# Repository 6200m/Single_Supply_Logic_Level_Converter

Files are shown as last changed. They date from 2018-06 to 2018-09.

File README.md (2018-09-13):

SparkFun Single Supply Logic Level Converter
========================================

Single Supply Logic Level Converter (https://cdn.sparkfun.com/assets/parts/1/3/0/1/0/14765-SparkFun_Logic_Level_Converter_-_Single_Supply-01.jpg)

[*SparkFun Single Supply Logic Level Converter (PRT-14765)*](https://www.sparkfun.com/products/14765)

The SparkFun Single Supply Logic Level Converter is logic level and power supply translator in one small package. This little board breaks out the Texas Instruments TXB0104 4-bit bi-directional voltage-level translator with automatic direction sensing. With this logic level converter you will be able to use your 5V logic microcontroller with 3.3V sensors without the second power supply!

What makes this logic level converter truly special is the fact that you can supply it with 3.3V and it will create the 5V - meaning you can use your 3.3V system, and convert directly to another 5V sensor - and even power your sensor or other board!

This logic level converter provides 5V to the high side of the TXB0104 and the low side is programmable to 3.3V, 2.5V and 1.8V. Please keep in mind that the default low side voltage is 3.3V.

Repository Contents
-------------------
* **/Firmware** - Example code 
* **/Hardware** - Eagle design files (.brd, .sch)
* **/Production** - Production panel files (.brd)

Documentation
--------------
* **[Hookup Guide](https://learn.sparkfun.com/tutorials/single-supply-logic-level-converter-hook-up-guide)** - Basic hookup guide for the Single Supply Logic Level Converter.
* **[SparkFun Fritzing repo](https://github.com/sparkfun/Fritzing_Parts)** - Fritzing diagrams for SparkFun products.

Product Versions
----------------
* [PRT-14765](https://www.sparkfun.com/products/14765)- V1.0

License Information
-------------------

This product is _**open source**_! 

Please review the LICENSE.md file for license information. 

If you have any questions or concerns on licensing, please contact techsupport@sparkfun.com.

Distributed as-is; no warranty is given.

- Your friends at SparkFun.

_<COLLABORATION CREDIT>_

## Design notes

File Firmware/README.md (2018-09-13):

SparkFun <PRODUCT NAME> Firmware
=================================

Arduino example code used in the hookup guide for use with the single supply logic level converter.

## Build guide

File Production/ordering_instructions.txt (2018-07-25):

panel size, 221x156mm
PCB thickness, 1.6mm
number of layers, 2
soldermask color, Red
silkscreen color, White
oz copper, 1oz
finish, HASL lead free
stencils, none
pcs per panel, 40

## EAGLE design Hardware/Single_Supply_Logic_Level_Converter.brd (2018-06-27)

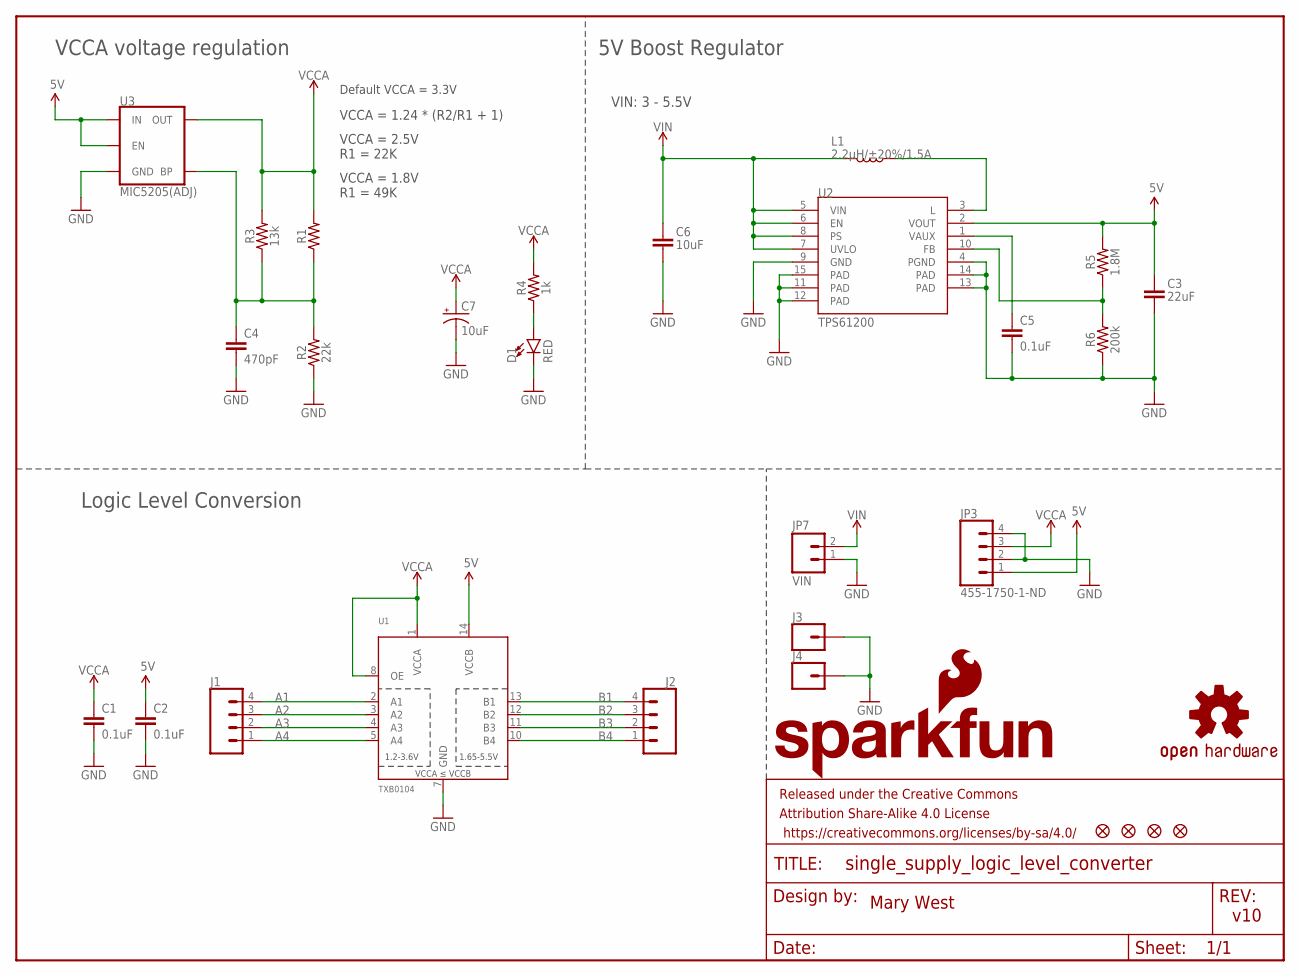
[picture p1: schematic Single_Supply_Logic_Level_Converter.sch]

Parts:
C1, C2: 0.1uF; 0603-CAP
C3: 22uF; 0805
C4: 470pF; 0603
C5: 0.1uF; 0603
C6: 10uF; 0603
C7: 10uF; EIA3216
D1: RED; LED-0603
FD1, FD2, FD3, FD4: FIDUCIALUFIDUCIAL; FIDUCIAL-MICRO
FRAME1: FRAME-LETTER; CREATIVE_COMMONS
J1, J2: CONN_04; 1X04
J3, J4: CONN_01; 1X01
JP3: 455-1750-1-ND; 1X04
JP7: VIN; 1X02
L1: 2.2µH/±20%/1.5A; INDUCTOR_2.2UH
LOGO1: SFE_LOGO_NAME_FLAME.1_INCH; SFE_LOGO_NAME_FLAME_.1
LOGO2: OSHW-LOGOS; OSHW-LOGO-S
R1: AXIAL-0.3
R2: 22k; 0603
R3: 13k; 0603
R4: 1k; 0603
R5: 1.8M; 0603
R6: 200k; 0603
U1: TXB0104; TSSOP14
U2: TPS61200; QFN-10_PAD
U3: MIC5205(ADJ); SOT23-5

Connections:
5V: C2.1, C3.1, JP3.1, R5.2, U1.14 (VCCB), U2.2 (VOUT), U3.1 (IN), U3.3 (EN)
A1: J1.4, U1.2 (A1)
A2: J1.3, U1.3 (A2)
A3: J1.2, U1.4 (A3)
A4: J1.1, U1.5 (A4)
B1: J2.4, U1.13 (B1)
B2: J2.3, U1.12 (B2)
B3: J2.2, U1.11 (B3)
B4: J2.1, U1.10 (B4)
FB: R5.1, R6.2, U2.10 (FB)
GND: C1.2, C2.2, C3.2, C4.2, C5.2, C6.2, C7.-, D1.C, J3.1, J4.1, JP3.2, JP3.4, JP7.1, R2.1, R6.1, U1.7 (GND), U2.4 (PGND), U2.9 (GND), U2.11 (PAD), U2.12 (PAD), U2.13 (PAD), U2.14 (PAD), U2.15 (PAD), U3.2 (GND)
unnamed: D1.A, R4.1
unnamed: L1.P$1 (1), U2.3 (L)
unnamed: C5.1, U2.1 (VAUX)
unnamed: C4.1, R1.P$1 (1), R2.2, R3.1, U3.4 (BP)
VCCA: C1.1, C7.+, JP3.3, R1.P$2 (2), R3.2, R4.2, U1.1 (VCCA), U1.8 (OE), U3.5 (OUT)
VIN: C6.1, JP7.2, L1.P$2 (2), U2.5 (VIN), U2.6 (EN), U2.7 (UVLO), U2.8 (PS)

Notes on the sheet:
Mary West
v10
VIN: 3 - 5.5V
Default VCCA = 3.3V
Logic Level Conversion
VCCA voltage regulation
5V Boost Regulator
VCCA = 1.24 * (R2/R1 + 1)
VCCA = 2.5V R1 = 22K
VCCA = 1.8V R1 = 49K

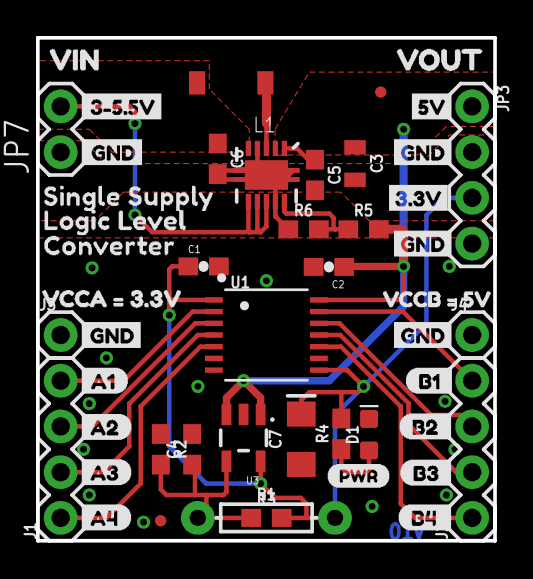
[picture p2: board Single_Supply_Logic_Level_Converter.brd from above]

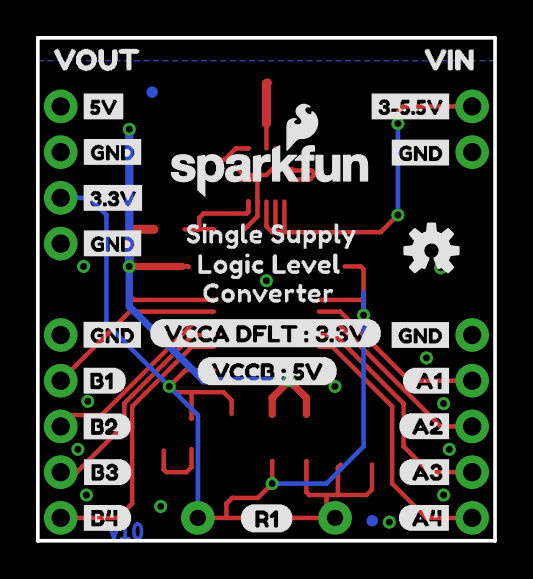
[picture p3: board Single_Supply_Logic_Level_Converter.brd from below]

Board: 2 copper layers, 25.4 x 27.9 mm, 79 parts (28 on the bottom side), 17 nets.

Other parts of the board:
U$7, U$24, U$31, U$34, U$35, U$40, U$41, U$52, U$54, U$55: GND0
U$8, U$38: VIN1
U$9: A10
U$10, U$43: CONVERTER0
U$11, U$45: LOGIC_LEVEL2
U$12, U$46: SINGLE_SUPPLY1
U$13: B1_12
U$14: A21
U$15: A32
U$16: A43
U$17: B14
U$18: B25
U$19: B2_11
U$20: B3_10
U$21, U$39: 3#5#5V3
U$22: B4_9
U$23, U$53: 3#3V2
U$25: A14
U$26: A28
U$27, U$44: VOUT2
U$28: A35
U$29: PWR0
U$30: A46
U$32, U$51: 5V1
U$33: B36
U$36: VCCA_#_3#3V0
U$42: B47
U$47: VCCA_DFLT_#_3#3V0
U$48: VCCB_#_5V0
U$49: R10
U$56: VCCB_#_5V1

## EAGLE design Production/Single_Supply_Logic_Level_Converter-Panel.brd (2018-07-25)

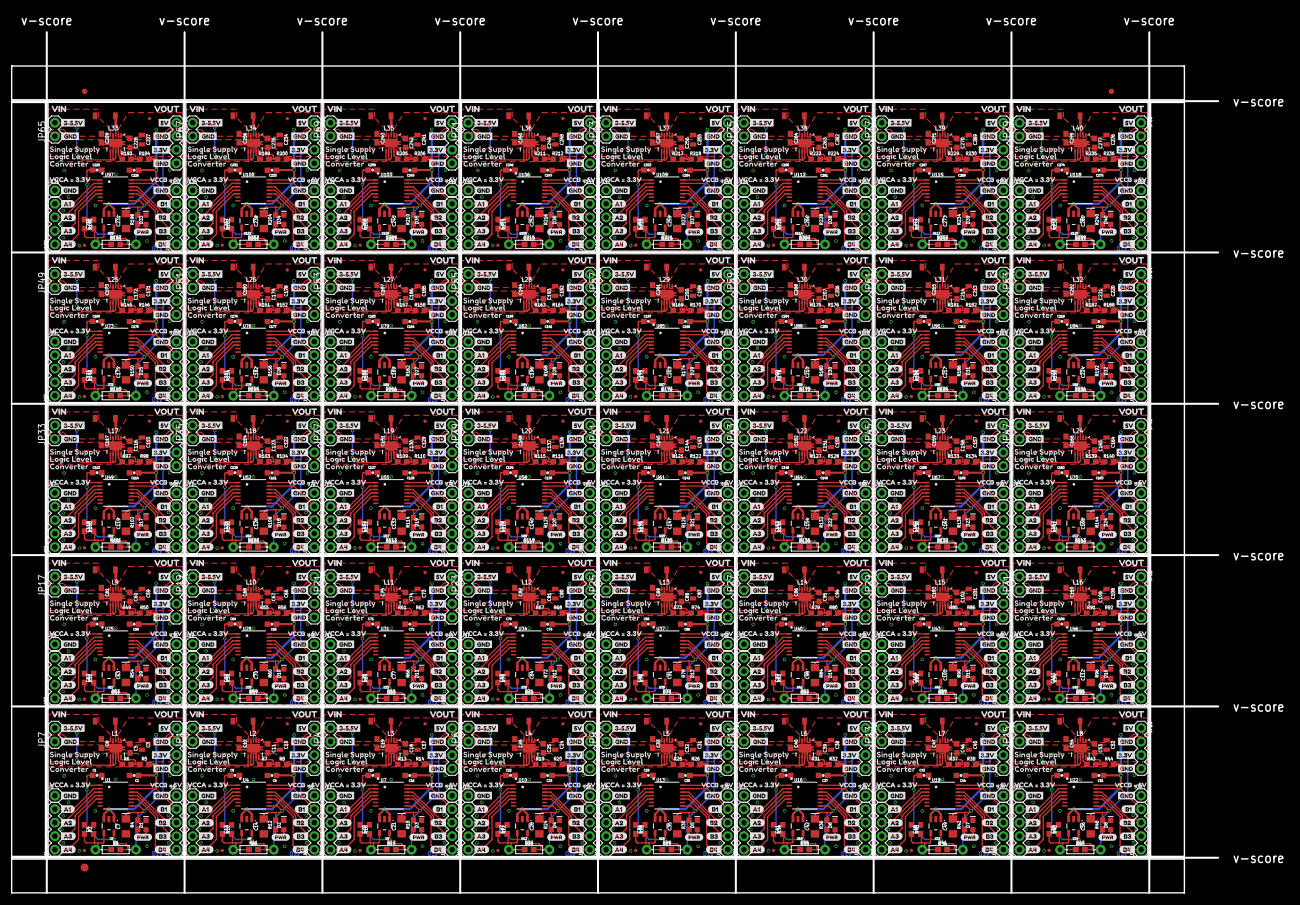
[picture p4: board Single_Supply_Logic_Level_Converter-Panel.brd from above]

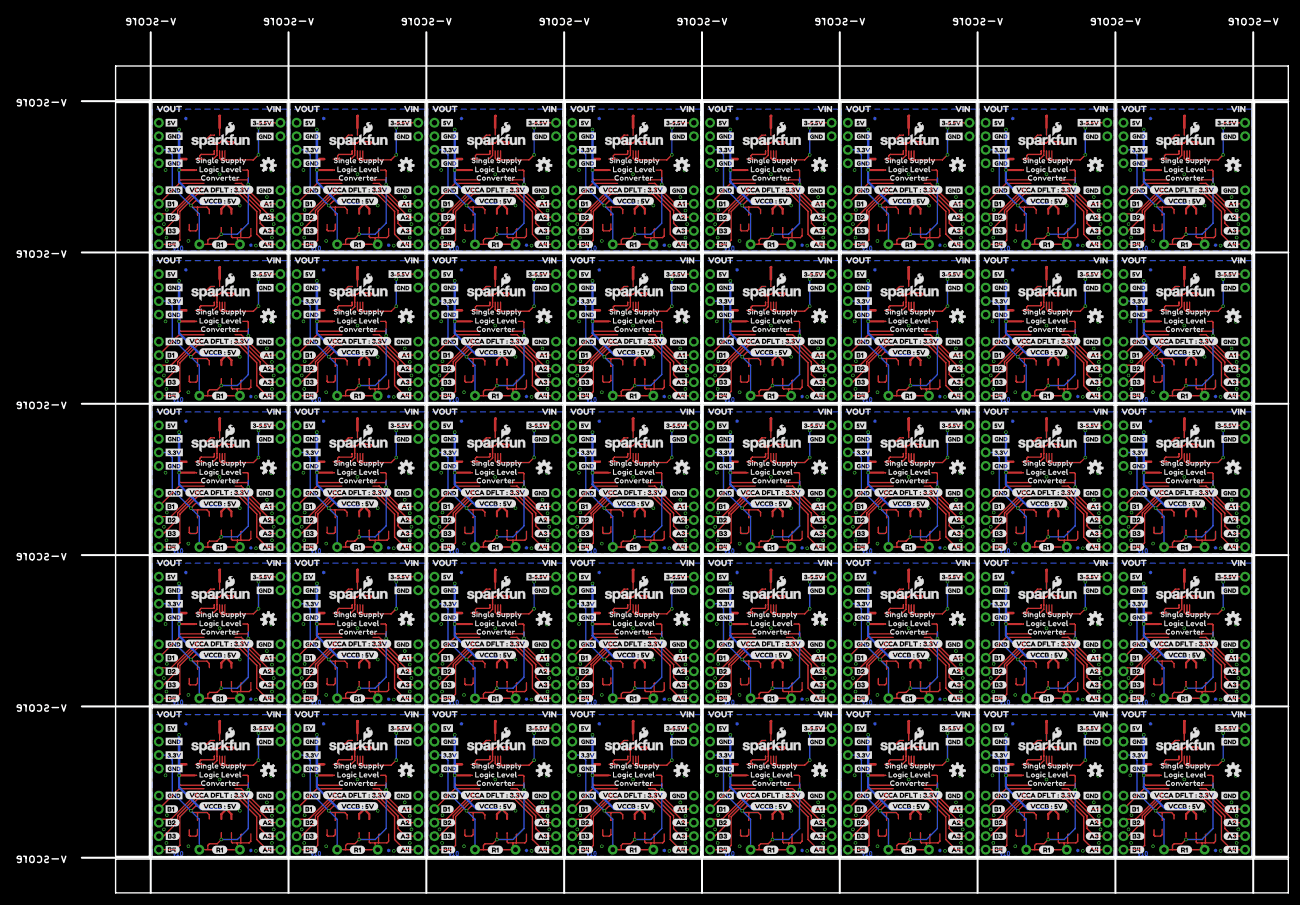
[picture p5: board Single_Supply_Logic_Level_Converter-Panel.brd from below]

Board: 2 copper layers, 226.8 x 161.8 mm, 3123 parts (1120 on the bottom side), 680 nets.

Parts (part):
C1, C2, C8, C9, C15, C16, C22, C23, C29, C30, C36, C37, C43, C44, C50, C51, C57, C58, C64, C65, C71, C72, C78, C79, C85, C86, C92, C93, C99, C100, C106, C107, C113, C114, C120, C121, C127, C128, C134, C135, C141, C142, C148, C149, C155, C156, C162, C163, C169, C170, C176, C177, C183, C184, C190, C191, C197, C198, C204, C205, C211, C212, C218, C219, C225, C226, C232, C233, C239, C240, C246, C247, C253, C254, C260, C261, C267, C268, C274, C275: 0.1uF; 0603-CAP
C3, C10, C17, C24, C31, C38, C45, C52, C59, C66, C73, C80, C87, C94, C101, C108, C115, C122, C129, C136, C143, C150, C157, C164, C171, C178, C185, C192, C199, C206, C213, C220, C227, C234, C241, C248, C255, C262, C269, C276: 22uF; 0805
C4, C13, C20, C27, C34, C41, C48, C55, C62, C69, C76, C83, C90, C97, C104, C111, C118, C125, C132, C139, C146, C153, C160, C167, C174, C181, C188, C195, C202, C209, C216, C223, C230, C237, C244, C251, C258, C265, C272, C279: 470pF; 0603
C5, C11, C18, C25, C32, C39, C46, C53, C60, C67, C74, C81, C88, C95, C102, C109, C116, C123, C130, C137, C144, C151, C158, C165, C172, C179, C186, C193, C200, C207, C214, C221, C228, C235, C242, C249, C256, C263, C270, C277: 0.1uF; 0603
C6, C12, C19, C26, C33, C40, C47, C54, C61, C68, C75, C82, C89, C96, C103, C110, C117, C124, C131, C138, C145, C152, C159, C166, C173, C180, C187, C194, C201, C208, C215, C222, C229, C236, C243, C250, C257, C264, C271, C278: 10uF; 0603
C7, C14, C21, C28, C35, C42, C49, C56, C63, C70, C77, C84, C91, C98, C105, C112, C119, C126, C133, C140, C147, C154, C161, C168, C175, C182, C189, C196, C203, C210, C217, C224, C231, C238, C245, C252, C259, C266, C273, C280: 10uF; EIA3216
D1, D2, D3, D4, D5, D6, D7, D8, D9, D10, D11, D12, D13, D14, D15, D16, D17, D18, D19, D20, D21, D22, D23, D24, D25, D26, D27, D28, D29, D30, D31, D32, D33, D34, D35, D36, D37, D38, D39, D40: RED; LED-0603
E$1, E$2: FIDUCIAL-1X2
E$3: FIDUCIAL-1.5X3
FD1, FD2, FD3, FD4, FD5, FD6, FD7, FD8, FD9, FD10, FD11, FD12, FD13, FD14, FD15, FD16, FD17, FD18, FD19, FD20, FD21, FD22, FD23, FD24, FD25, FD26, FD27, FD28, FD29, FD30, FD31, FD32, FD33, FD34, FD35, FD36, FD37, FD38, FD39, FD40, FD41, FD42, FD43, FD44, FD45, FD46, FD47, FD48, FD49, FD50, FD51, FD52, FD53, FD54, FD55, FD56, FD57, FD58, FD59, FD60, FD61, FD62, FD63, FD64, FD65, FD66, FD67, FD68, FD69, FD70, FD71, FD72, FD73, FD74, FD75, FD76, FD77, FD78, FD79, FD80, FD81, FD82, FD83, FD84, FD85, FD86, FD87, FD88, FD89, FD90, FD91, FD92, FD93, FD94, FD95, FD96, FD97, FD98, FD99, FD100, FD101, FD102, FD103, FD104, FD105, FD106, FD107, FD108, FD109, FD110, FD111, FD112, FD113, FD114, FD115, FD116, FD117, FD118, FD119, FD120, FD121, FD122, FD123, FD124, FD125, FD126, FD127, FD128, FD129, FD130, FD131, FD132, FD133, FD134, FD135, FD136, FD137, FD138, FD139, FD140, FD141, FD142, FD143, FD144, FD145, FD146, FD147, FD148, FD149, FD150, FD151, FD152, FD153, FD154, FD155, FD156, FD157, FD158, FD159, FD160: FIDUCIALUFIDUCIAL; FIDUCIAL-MICRO
J1, J2, J5, J6, J9, J10, J13, J14, J17, J18, J21, J22, J25, J26, J29, J30, J33, J34, J37, J38, J41, J42, J45, J46, J49, J50, J53, J54, J57, J58, J61, J62, J65, J66, J69, J70, J73, J74, J77, J78, J81, J82, J85, J86, J89, J90, J93, J94, J97, J98, J101, J102, J105, J106, J109, J110, J113, J114, J117, J118, J121, J122, J125, J126, J129, J130, J133, J134, J137, J138, J141, J142, J145, J146, J149, J150, J153, J154, J157, J158: 1X04
J3, J4, J7, J8, J11, J12, J15, J16, J19, J20, J23, J24, J27, J28, J31, J32, J35, J36, J39, J40, J43, J44, J47, J48, J51, J52, J55, J56, J59, J60, J63, J64, J67, J68, J71, J72, J75, J76, J79, J80, J83, J84, J87, J88, J91, J92, J95, J96, J99, J100, J103, J104, J107, J108, J111, J112, J115, J116, J119, J120, J123, J124, J127, J128, J131, J132, J135, J136, J139, J140, J143, J144, J147, J148, J151, J152, J155, J156, J159, J160: 1X01
JP1, JP4, JP6, JP7, JP9, JP11, JP13, JP15, JP17, JP19, JP21, JP23, JP25, JP27, JP29, JP31, JP33, JP35, JP37, JP39, JP41, JP43, JP45, JP47, JP49, JP51, JP53, JP55, JP57, JP59, JP61, JP63, JP65, JP67, JP69, JP71, JP73, JP75, JP77, JP79: VIN; 1X02
JP2, JP3, JP5, JP8, JP10, JP12, JP14, JP16, JP18, JP20, JP22, JP24, JP26, JP28, JP30, JP32, JP34, JP36, JP38, JP40, JP42, JP44, JP46, JP48, JP50, JP52, JP54, JP56, JP58, JP60, JP62, JP64, JP66, JP68, JP70, JP72, JP74, JP76, JP78, JP80: 455-1750-1-ND; 1X04
L1, L2, L3, L4, L5, L6, L7, L8, L9, L10, L11, L12, L13, L14, L15, L16, L17, L18, L19, L20, L21, L22, L23, L24, L25, L26, L27, L28, L29, L30, L31, L32, L33, L34, L35, L36, L37, L38, L39, L40: 2.2µH/±20%/1.5A; INDUCTOR_2.2UH
LOGO1, LOGO4, LOGO6, LOGO8, LOGO10, LOGO12, LOGO14, LOGO16, LOGO18, LOGO20, LOGO22, LOGO24, LOGO26, LOGO28, LOGO30, LOGO32, LOGO34, LOGO36, LOGO38, LOGO40, LOGO42, LOGO44, LOGO46, LOGO48, LOGO50, LOGO52, LOGO54, LOGO56, LOGO58, LOGO60, LOGO62, LOGO64, LOGO66, LOGO68, LOGO70, LOGO72, LOGO74, LOGO76, LOGO78, LOGO80: SFE_LOGO_NAME_FLAME.1_INCH; SFE_LOGO_NAME_FLAME_.1
LOGO2, LOGO3, LOGO5, LOGO7, LOGO9, LOGO11, LOGO13, LOGO15, LOGO17, LOGO19, LOGO21, LOGO23, LOGO25, LOGO27, LOGO29, LOGO31, LOGO33, LOGO35, LOGO37, LOGO39, LOGO41, LOGO43, LOGO45, LOGO47, LOGO49, LOGO51, LOGO53, LOGO55, LOGO57, LOGO59, LOGO61, LOGO63, LOGO65, LOGO67, LOGO69, LOGO71, LOGO73, LOGO75, LOGO77, LOGO79: OSHW-LOGOS; OSHW-LOGO-S
R1, R11, R17, R23, R29, R35, R41, R47, R53, R59, R65, R71, R77, R83, R89, R95, R101, R107, R113, R119, R125, R131, R137, R143, R149, R155, R161, R167, R173, R179, R185, R191, R197, R203, R209, R215, R221, R227, R233, R239: AXIAL-0.3
R2, R10, R16, R22, R28, R34, R40, R46, R52, R58, R64, R70, R76, R82, R88, R94, R100, R106, R112, R118, R124, R130, R136, R142, R148, R154, R160, R166, R172, R178, R184, R190, R196, R202, R208, R214, R220, R226, R232, R238: 22k; 0603
R3, R9, R15, R21, R27, R33, R39, R45, R51, R57, R63, R69, R75, R81, R87, R93, R99, R105, R111, R117, R123, R129, R135, R141, R147, R153, R159, R165, R171, R177, R183, R189, R195, R201, R207, R213, R219, R225, R231, R237: 13k; 0603
R4, R12, R18, R24, R30, R36, R42, R48, R54, R60, R66, R72, R78, R84, R90, R96, R102, R108, R114, R120, R126, R132, R138, R144, R150, R156, R162, R168, R174, R180, R186, R192, R198, R204, R210, R216, R222, R228, R234, R240: 1k; 0603
R5, R8, R14, R20, R26, R32, R38, R44, R50, R56, R62, R68, R74, R80, R86, R92, R98, R104, R110, R116, R122, R128, R134, R140, R146, R152, R158, R164, R170, R176, R182, R188, R194, R200, R206, R212, R218, R224, R230, R236: 1.8M; 0603
R6, R7, R13, R19, R25, R31, R37, R43, R49, R55, R61, R67, R73, R79, R85, R91, R97, R103, R109, R115, R121, R127, R133, R139, R145, R151, R157, R163, R169, R175, R181, R187, R193, R199, R205, R211, R217, R223, R229, R235: 200k; 0603
U1, U4, U7, U10, U13, U16, U19, U22, U25, U28, U31, U34, U37, U40, U43, U46, U49, U52, U55, U58, U61, U64, U67, U70, U73, U76, U79, U82, U85, U88, U91, U94, U97, U100, U103, U106, U109, U112, U115, U118: TXB0104; TSSOP14
U2, U5, U8, U11, U14, U17, U20, U23, U26, U29, U32, U35, U38, U41, U44, U47, U50, U53, U56, U59, U62, U65, U68, U71, U74, U77, U80, U83, U86, U89, U92, U95, U98, U101, U104, U107, U110, U113, U116, U119: TPS61200; QFN-10_PAD
U3, U6, U9, U12, U15, U18, U21, U24, U27, U30, U33, U36, U39, U42, U45, U48, U51, U54, U57, U60, U63, U66, U69, U72, U75, U78, U81, U84, U87, U90, U93, U96, U99, U102, U105, U108, U111, U114, U117, U120: MIC5205(ADJ); SOT23-5
U$1, U$29, U$97, U$145, U$193, U$241, U$289, U$337, U$385, U$433, U$481, U$529, U$577, U$625, U$673, U$721, U$769, U$817, U$865, U$913, U$961, U$1009, U$1057, U$1105, U$1153, U$1201, U$1249, U$1297, U$1345, U$1393, U$1441, U$1489, U$1537, U$1585, U$1633, U$1681, U$1729, U$1777, U$1825, U$1873: PWR0
U$2, U$5, U$10, U$43, U$98, U$101, U$146, U$149, U$194, U$197, U$242, U$245, U$290, U$293, U$338, U$341, U$386, U$389, U$434, U$437, U$482, U$485, U$530, U$533, U$578, U$581, U$626, U$629, U$674, U$677, U$722, U$725, U$770, U$773, U$818, U$821, U$866, U$869, U$914, U$917, U$962, U$965, U$1010, U$1013, U$1058, U$1061, U$1106, U$1109, U$1154, U$1157, U$1202, U$1205, U$1250, U$1253, U$1298, U$1301, U$1346, U$1349, U$1394, U$1397, U$1442, U$1445, U$1490, U$1493, U$1538, U$1541, U$1586, U$1589, U$1634, U$1637, U$1682, U$1685, U$1730, U$1733, U$1778, U$1781, U$1826, U$1829, U$1874, U$1877: CONVERTER0
U$3, U$6, U$11, U$45, U$99, U$102, U$147, U$150, U$195, U$198, U$243, U$246, U$291, U$294, U$339, U$342, U$387, U$390, U$435, U$438, U$483, U$486, U$531, U$534, U$579, U$582, U$627, U$630, U$675, U$678, U$723, U$726, U$771, U$774, U$819, U$822, U$867, U$870, U$915, U$918, U$963, U$966, U$1011, U$1014, U$1059, U$1062, U$1107, U$1110, U$1155, U$1158, U$1203, U$1206, U$1251, U$1254, U$1299, U$1302, U$1347, U$1350, U$1395, U$1398, U$1443, U$1446, U$1491, U$1494, U$1539, U$1542, U$1587, U$1590, U$1635, U$1638, U$1683, U$1686, U$1731, U$1734, U$1779, U$1782, U$1827, U$1830, U$1875, U$1878: LOGIC_LEVEL2
U$4, U$12, U$37, U$46, U$100, U$103, U$148, U$151, U$196, U$199, U$244, U$247, U$292, U$295, U$340, U$343, U$388, U$391, U$436, U$439, U$484, U$487, U$532, U$535, U$580, U$583, U$628, U$631, U$676, U$679, U$724, U$727, U$772, U$775, U$820, U$823, U$868, U$871, U$916, U$919, U$964, U$967, U$1012, U$1015, U$1060, U$1063, U$1108, U$1111, U$1156, U$1159, U$1204, U$1207, U$1252, U$1255, U$1300, U$1303, U$1348, U$1351, U$1396, U$1399, U$1444, U$1447, U$1492, U$1495, U$1540, U$1543, U$1588, U$1591, U$1636, U$1639, U$1684, U$1687, U$1732, U$1735, U$1780, U$1783, U$1828, U$1831, U$1876, U$1879: SINGLE_SUPPLY1
U$7, U$24, U$31, U$34, U$35, U$40, U$41, U$52, U$54, U$55, U$57, U$58, U$68, U$70, U$71, U$73, U$74, U$76, U$78, U$79, U$105, U$106, U$116, U$118, U$119, U$121, U$122, U$124, U$126, U$127, U$153, U$154, U$164, U$166, U$167, U$169, U$170, U$172, U$174, U$175, U$201, U$202, U$212, U$214, U$215, U$217, U$218, U$220, U$222, U$223, U$249, U$250, U$260, U$262, U$263, U$265, U$266, U$268, U$270, U$271, U$297, U$298, U$308, U$310, U$311, U$313, U$314, U$316, U$318, U$319, U$345, U$346, U$356, U$358, U$359, U$361, U$362, U$364, U$366, U$367, U$393, U$394, U$404, U$406, U$407, U$409, U$410, U$412, U$414, U$415, U$441, U$442, U$452, U$454, U$455, U$457, U$458, U$460, U$462, U$463, U$489, U$490, U$500, U$502, U$503, U$505, U$506, U$508, U$510, U$511, U$537, U$538, U$548, U$550, U$551, U$553, U$554, U$556, U$558, U$559, U$585, U$586, U$596, U$598, U$599, U$601, U$602, U$604, U$606, U$607, U$633, U$634, U$644, U$646, U$647, U$649, U$650, U$652, U$654, U$655, U$681, U$682, U$692, U$694, U$695, U$697, U$698, U$700, U$702, U$703, U$729, U$730, U$740, U$742, U$743, U$745, U$746, U$748, U$750, U$751, U$777, U$778, U$788, U$790, U$791, U$793, U$794, U$796, U$798, U$799, U$825, U$826, U$836, U$838, U$839, U$841, U$842, U$844, U$846, U$847, U$873, U$874, U$884, U$886, U$887, U$889, U$890, U$892, U$894, U$895, U$921, U$922, U$932, U$934, U$935, U$937, U$938, U$940, U$942, U$943, U$969, U$970, U$980, U$982, U$983, U$985, U$986, U$988, U$990, U$991, U$1017, U$1018, U$1028, U$1030, U$1031, U$1033, U$1034, U$1036, U$1038, U$1039, U$1065, U$1066, U$1076, U$1078, U$1079, U$1081, U$1082, U$1084, U$1086, U$1087, U$1113, U$1114, U$1124, U$1126, U$1127, U$1129, U$1130, U$1132, U$1134, U$1135, U$1161, U$1162, U$1172, U$1174, U$1175, U$1177, U$1178, U$1180, U$1182, U$1183, U$1209, U$1210, U$1220, U$1222, U$1223, U$1225, U$1226, U$1228, U$1230, U$1231, U$1257, U$1258, U$1268, U$1270, U$1271, U$1273, U$1274, U$1276, U$1278, U$1279, U$1305, U$1306, U$1316, U$1318, U$1319, U$1321, U$1322, U$1324, U$1326, U$1327, U$1353, U$1354, U$1364, U$1366, U$1367, U$1369, U$1370, U$1372, U$1374, U$1375, U$1401, U$1402, U$1412, U$1414, U$1415, U$1417, U$1418, U$1420, U$1422, U$1423, U$1449, U$1450, U$1460, U$1462, U$1463, U$1465, U$1466, U$1468, U$1470, U$1471, U$1497, U$1498, U$1508, U$1510, U$1511, U$1513, U$1514, U$1516, U$1518, U$1519, U$1545, U$1546, U$1556, U$1558, U$1559, U$1561, U$1562, U$1564, U$1566, U$1567, U$1593, U$1594, U$1604, U$1606, U$1607, U$1609, U$1610, U$1612, U$1614, U$1615, U$1641, U$1642, U$1652, U$1654, U$1655, U$1657, U$1658, U$1660, U$1662, U$1663, U$1689, U$1690, U$1700, U$1702, U$1703, U$1705, U$1706, U$1708, U$1710, U$1711, U$1737, U$1738, U$1748, U$1750, U$1751, U$1753, U$1754, U$1756, U$1758, U$1759, U$1785, U$1786, U$1796, U$1798, U$1799, U$1801, U$1802, U$1804, U$1806, U$1807, U$1833, U$1834, U$1844, U$1846, U$1847, U$1849, U$1850, U$1852, U$1854, U$1855, U$1881, U$1882, U$1892, U$1894, U$1895, U$1897, U$1898, U$1900, U$1902, U$1903: GND0
U$8, U$38, U$88, U$92, U$136, U$140, U$184, U$188, U$232, U$236, U$280, U$284, U$328, U$332, U$376, U$380, U$424, U$428, U$472, U$476, U$520, U$524, U$568, U$572, U$616, U$620, U$664, U$668, U$712, U$716, U$760, U$764, U$808, U$812, U$856, U$860, U$904, U$908, U$952, U$956, U$1000, U$1004, U$1048, U$1052, U$1096, U$1100, U$1144, U$1148, U$1192, U$1196, U$1240, U$1244, U$1288, U$1292, U$1336, U$1340, U$1384, U$1388, U$1432, U$1436, U$1480, U$1484, U$1528, U$1532, U$1576, U$1580, U$1624, U$1628, U$1672, U$1676, U$1720, U$1724, U$1768, U$1772, U$1816, U$1820, U$1864, U$1868, U$1912, U$1916: VIN1
U$9, U$80, U$128, U$176, U$224, U$272, U$320, U$368, U$416, U$464, U$512, U$560, U$608, U$656, U$704, U$752, U$800, U$848, U$896, U$944, U$992, U$1040, U$1088, U$1136, U$1184, U$1232, U$1280, U$1328, U$1376, U$1424, U$1472, U$1520, U$1568, U$1616, U$1664, U$1712, U$1760, U$1808, U$1856, U$1904: A10
U$13, U$63, U$111, U$159, U$207, U$255, U$303, U$351, U$399, U$447, U$495, U$543, U$591, U$639, U$687, U$735, U$783, U$831, U$879, U$927, U$975, U$1023, U$1071, U$1119, U$1167, U$1215, U$1263, U$1311, U$1359, U$1407, U$1455, U$1503, U$1551, U$1599, U$1647, U$1695, U$1743, U$1791, U$1839, U$1887: B1_12
U$14, U$81, U$129, U$177, U$225, U$273, U$321, U$369, U$417, U$465, U$513, U$561, U$609, U$657, U$705, U$753, U$801, U$849, U$897, U$945, U$993, U$1041, U$1089, U$1137, U$1185, U$1233, U$1281, U$1329, U$1377, U$1425, U$1473, U$1521, U$1569, U$1617, U$1665, U$1713, U$1761, U$1809, U$1857, U$1905: A21
U$15, U$82, U$130, U$178, U$226, U$274, U$322, U$370, U$418, U$466, U$514, U$562, U$610, U$658, U$706, U$754, U$802, U$850, U$898, U$946, U$994, U$1042, U$1090, U$1138, U$1186, U$1234, U$1282, U$1330, U$1378, U$1426, U$1474, U$1522, U$1570, U$1618, U$1666, U$1714, U$1762, U$1810, U$1858, U$1906: A32
U$16, U$83, U$131, U$179, U$227, U$275, U$323, U$371, U$419, U$467, U$515, U$563, U$611, U$659, U$707, U$755, U$803, U$851, U$899, U$947, U$995, U$1043, U$1091, U$1139, U$1187, U$1235, U$1283, U$1331, U$1379, U$1427, U$1475, U$1523, U$1571, U$1619, U$1667, U$1715, U$1763, U$1811, U$1859, U$1907: A43
U$17, U$84, U$132, U$180, U$228, U$276, U$324, U$372, U$420, U$468, U$516, U$564, U$612, U$660, U$708, U$756, U$804, U$852, U$900, U$948, U$996, U$1044, U$1092, U$1140, U$1188, U$1236, U$1284, U$1332, U$1380, U$1428, U$1476, U$1524, U$1572, U$1620, U$1668, U$1716, U$1764, U$1812, U$1860, U$1908: B14
U$18, U$85, U$133, U$181, U$229, U$277, U$325, U$373, U$421, U$469, U$517, U$565, U$613, U$661, U$709, U$757, U$805, U$853, U$901, U$949, U$997, U$1045, U$1093, U$1141, U$1189, U$1237, U$1285, U$1333, U$1381, U$1429, U$1477, U$1525, U$1573, U$1621, U$1669, U$1717, U$1765, U$1813, U$1861, U$1909: B25
U$19, U$64, U$112, U$160, U$208, U$256, U$304, U$352, U$400, U$448, U$496, U$544, U$592, U$640, U$688, U$736, U$784, U$832, U$880, U$928, U$976, U$1024, U$1072, U$1120, U$1168, U$1216, U$1264, U$1312, U$1360, U$1408, U$1456, U$1504, U$1552, U$1600, U$1648, U$1696, U$1744, U$1792, U$1840, U$1888: B2_11
U$20, U$65, U$113, U$161, U$209, U$257, U$305, U$353, U$401, U$449, U$497, U$545, U$593, U$641, U$689, U$737, U$785, U$833, U$881, U$929, U$977, U$1025, U$1073, U$1121, U$1169, U$1217, U$1265, U$1313, U$1361, U$1409, U$1457, U$1505, U$1553, U$1601, U$1649, U$1697, U$1745, U$1793, U$1841, U$1889: B3_10
U$21, U$39, U$50, U$72, U$104, U$120, U$152, U$168, U$200, U$216, U$248, U$264, U$296, U$312, U$344, U$360, U$392, U$408, U$440, U$456, U$488, U$504, U$536, U$552, U$584, U$600, U$632, U$648, U$680, U$696, U$728, U$744, U$776, U$792, U$824, U$840, U$872, U$888, U$920, U$936, U$968, U$984, U$1016, U$1032, U$1064, U$1080, U$1112, U$1128, U$1160, U$1176, U$1208, U$1224, U$1256, U$1272, U$1304, U$1320, U$1352, U$1368, U$1400, U$1416, U$1448, U$1464, U$1496, U$1512, U$1544, U$1560, U$1592, U$1608, U$1640, U$1656, U$1688, U$1704, U$1736, U$1752, U$1784, U$1800, U$1832, U$1848, U$1880, U$1896: 3#5#5V3
U$22, U$66, U$114, U$162, U$210, U$258, U$306, U$354, U$402, U$450, U$498, U$546, U$594, U$642, U$690, U$738, U$786, U$834, U$882, U$930, U$978, U$1026, U$1074, U$1122, U$1170, U$1218, U$1266, U$1314, U$1362, U$1410, U$1458, U$1506, U$1554, U$1602, U$1650, U$1698, U$1746, U$1794, U$1842, U$1890: B4_9
U$23, U$53, U$67, U$77, U$115, U$125, U$163, U$173, U$211, U$221, U$259, U$269, U$307, U$317, U$355, U$365, U$403, U$413, U$451, U$461, U$499, U$509, U$547, U$557, U$595, U$605, U$643, U$653, U$691, U$701, U$739, U$749, U$787, U$797, U$835, U$845, U$883, U$893, U$931, U$941, U$979, U$989, U$1027, U$1037, U$1075, U$1085, U$1123, U$1133, U$1171, U$1181, U$1219, U$1229, U$1267, U$1277, U$1315, U$1325, U$1363, U$1373, U$1411, U$1421, U$1459, U$1469, U$1507, U$1517, U$1555, U$1565, U$1603, U$1613, U$1651, U$1661, U$1699, U$1709, U$1747, U$1757, U$1795, U$1805, U$1843, U$1853, U$1891, U$1901: 3#3V2
U$25, U$59, U$107, U$155, U$203, U$251, U$299, U$347, U$395, U$443, U$491, U$539, U$587, U$635, U$683, U$731, U$779, U$827, U$875, U$923, U$971, U$1019, U$1067, U$1115, U$1163, U$1211, U$1259, U$1307, U$1355, U$1403, U$1451, U$1499, U$1547, U$1595, U$1643, U$1691, U$1739, U$1787, U$1835, U$1883: A14
U$26, U$60, U$108, U$156, U$204, U$252, U$300, U$348, U$396, U$444, U$492, U$540, U$588, U$636, U$684, U$732, U$780, U$828, U$876, U$924, U$972, U$1020, U$1068, U$1116, U$1164, U$1212, U$1260, U$1308, U$1356, U$1404, U$1452, U$1500, U$1548, U$1596, U$1644, U$1692, U$1740, U$1788, U$1836, U$1884: A28
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

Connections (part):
5V: C2.1, C3.1, JP3.1, R5.2, U1.14, U2.2, U3.1, U3.3
5V1: C9.1, C10.1, JP2.1, R8.2, U4.14, U5.2, U6.1, U6.3
5V2: C16.1, C17.1, JP5.1, R14.2, U7.14, U8.2, U9.1, U9.3
5V3: C23.1, C24.1, JP8.1, R20.2, U10.14, U11.2, U12.1, U12.3
5V4: C30.1, C31.1, JP10.1, R26.2, U13.14, U14.2, U15.1, U15.3
5V5: C37.1, C38.1, JP12.1, R32.2, U16.14, U17.2, U18.1, U18.3
5V6: C44.1, C45.1, JP14.1, R38.2, U19.14, U20.2, U21.1, U21.3
5V7: C51.1, C52.1, JP16.1, R44.2, U22.14, U23.2, U24.1, U24.3
5V8: C58.1, C59.1, JP18.1, R50.2, U25.14, U26.2, U27.1, U27.3
5V9: C65.1, C66.1, JP20.1, R56.2, U28.14, U29.2, U30.1, U30.3
5V10: C72.1, C73.1, JP22.1, R62.2, U31.14, U32.2, U33.1, U33.3
5V11: C79.1, C80.1, JP24.1, R68.2, U34.14, U35.2, U36.1, U36.3
5V12: C86.1, C87.1, JP26.1, R74.2, U37.14, U38.2, U39.1, U39.3
5V13: C93.1, C94.1, JP28.1, R80.2, U40.14, U41.2, U42.1, U42.3
5V14: C100.1, C101.1, JP30.1, R86.2, U43.14, U44.2, U45.1, U45.3
5V15: C107.1, C108.1, JP32.1, R92.2, U46.14, U47.2, U48.1, U48.3
5V16: C114.1, C115.1, JP34.1, R98.2, U49.14, U50.2, U51.1, U51.3
5V17: C121.1, C122.1, JP36.1, R104.2, U52.14, U53.2, U54.1, U54.3
5V18: C128.1, C129.1, JP38.1, R110.2, U55.14, U56.2, U57.1, U57.3
5V19: C135.1, C136.1, JP40.1, R116.2, U58.14, U59.2, U60.1, U60.3
5V20: C142.1, C143.1, JP42.1, R122.2, U61.14, U62.2, U63.1, U63.3
5V21: C149.1, C150.1, JP44.1, R128.2, U64.14, U65.2, U66.1, U66.3
5V22: C156.1, C157.1, JP46.1, R134.2, U67.14, U68.2, U69.1, U69.3
5V23: C163.1, C164.1, JP48.1, R140.2, U70.14, U71.2, U72.1, U72.3
5V24: C170.1, C171.1, JP50.1, R146.2, U73.14, U74.2, U75.1, U75.3
5V25: C177.1, C178.1, JP52.1, R152.2, U76.14, U77.2, U78.1, U78.3
5V26: C184.1, C185.1, JP54.1, R158.2, U79.14, U80.2, U81.1, U81.3
5V27: C191.1, C192.1, JP56.1, R164.2, U82.14, U83.2, U84.1, U84.3
5V28: C198.1, C199.1, JP58.1, R170.2, U85.14, U86.2, U87.1, U87.3
5V29: C205.1, C206.1, JP60.1, R176.2, U88.14, U89.2, U90.1, U90.3
5V30: C212.1, C213.1, JP62.1, R182.2, U91.14, U92.2, U93.1, U93.3
5V31: C219.1, C220.1, JP64.1, R188.2, U94.14, U95.2, U96.1, U96.3
5V32: C226.1, C227.1, JP66.1, R194.2, U97.14, U98.2, U99.1, U99.3
5V33: C233.1, C234.1, JP68.1, R200.2, U100.14, U101.2, U102.1, U102.3
5V34: C240.1, C241.1, JP70.1, R206.2, U103.14, U104.2, U105.1, U105.3
5V35: C247.1, C248.1, JP72.1, R212.2, U106.14, U107.2, U108.1, U108.3
5V36: C254.1, C255.1, JP74.1, R218.2, U109.14, U110.2, U111.1, U111.3
5V37: C261.1, C262.1, JP76.1, R224.2, U112.14, U113.2, U114.1, U114.3
5V38: C268.1, C269.1, JP78.1, R230.2, U115.14, U116.2, U117.1, U117.3
5V39: C275.1, C276.1, JP80.1, R236.2, U118.14, U119.2, U120.1, U120.3
A1: J1.4, U1.2
A2: J1.3, U1.3
A3: J1.2, U1.4
A4: J1.1, U1.5
A5: J5.3, U4.3
A6: J5.1, U4.5
A7: J5.2, U4.4
A8: J5.4, U4.2
A9: J9.3, U7.3
A10: J9.1, U7.5
A11: J9.2, U7.4
A12: J9.4, U7.2
A13: J13.3, U10.3
A14: J13.1, U10.5
A15: J13.2, U10.4
A16: J13.4, U10.2
A17: J17.3, U13.3
A18: J17.1, U13.5
A19: J17.2, U13.4
A20: J17.4, U13.2
A21: J21.3, U16.3
A22: J21.1, U16.5
A23: J21.2, U16.4
A24: J21.4, U16.2
A25: J25.3, U19.3
A26: J25.1, U19.5
A27: J25.2, U19.4
A28: J25.4, U19.2
A29: J29.3, U22.3
A30: J29.1, U22.5
A31: J29.2, U22.4
A32: J29.4, U22.2
A33: J33.3, U25.3
A34: J33.1, U25.5
A35: J33.2, U25.4
A36: J33.4, U25.2
A37: J37.3, U28.3
A38: J37.1, U28.5
A39: J37.2, U28.4
A40: J37.4, U28.2
A41: J41.3, U31.3
A42: J41.1, U31.5
A43: J41.2, U31.4
A44: J41.4, U31.2
A45: J45.3, U34.3
A46: J45.1, U34.5
A47: J45.2, U34.4
A48: J45.4, U34.2
A49: J49.3, U37.3
A50: J49.1, U37.5
A51: J49.2, U37.4
A52: J49.4, U37.2
A53: J53.3, U40.3
A54: J53.1, U40.5
A55: J53.2, U40.4
A56: J53.4, U40.2
A57: J57.3, U43.3
A58: J57.1, U43.5
A59: J57.2, U43.4
A60: J57.4, U43.2
A61: J61.3, U46.3
A62: J61.1, U46.5
A63: J61.2, U46.4
A64: J61.4, U46.2
A65: J65.3, U49.3
A66: J65.1, U49.5
A67: J65.2, U49.4
A68: J65.4, U49.2
A69: J69.3, U52.3
A70: J69.1, U52.5
A71: J69.2, U52.4
A72: J69.4, U52.2
A73: J73.3, U55.3
A74: J73.1, U55.5
A75: J73.2, U55.4
A76: J73.4, U55.2
A77: J77.3, U58.3
A78: J77.1, U58.5
A79: J77.2, U58.4
A80: J77.4, U58.2
A81: J81.3, U61.3
A82: J81.1, U61.5
A83: J81.2, U61.4
A84: J81.4, U61.2
A85: J85.3, U64.3
A86: J85.1, U64.5
A87: J85.2, U64.4
A88: J85.4, U64.2
A89: J89.3, U67.3
A90: J89.1, U67.5
A91: J89.2, U67.4
A92: J89.4, U67.2
A93: J93.3, U70.3
A94: J93.1, U70.5
A95: J93.2, U70.4
A96: J93.4, U70.2
A97: J97.3, U73.3
A98: J97.1, U73.5
A99: J97.2, U73.4
A100: J97.4, U73.2
A101: J101.3, U76.3
A102: J101.1, U76.5
A103: J101.2, U76.4
A104: J101.4, U76.2
A105: J105.3, U79.3
A106: J105.1, U79.5
A107: J105.2, U79.4
A108: J105.4, U79.2
A109: J109.3, U82.3
A110: J109.1, U82.5
A111: J109.2, U82.4
A112: J109.4, U82.2
A113: J113.3, U85.3
A114: J113.1, U85.5
A115: J113.2, U85.4
A116: J113.4, U85.2
A117: J117.3, U88.3
A118: J117.1, U88.5
A119: J117.2, U88.4
A120: J117.4, U88.2
A121: J121.3, U91.3
A122: J121.1, U91.5
A123: J121.2, U91.4
A124: J121.4, U91.2
A125: J125.3, U94.3
A126: J125.1, U94.5
A127: J125.2, U94.4
A128: J125.4, U94.2
A129: J129.3, U97.3
A130: J129.1, U97.5
A131: J129.2, U97.4
A132: J129.4, U97.2
A133: J133.3, U100.3
A134: J133.1, U100.5
A135: J133.2, U100.4
A136: J133.4, U100.2
A137: J137.3, U103.3
A138: J137.1, U103.5
A139: J137.2, U103.4
A140: J137.4, U103.2
A141: J141.3, U106.3
A142: J141.1, U106.5
A143: J141.2, U106.4
A144: J141.4, U106.2
A145: J145.3, U109.3
A146: J145.1, U109.5
A147: J145.2, U109.4
A148: J145.4, U109.2
A149: J149.3, U112.3
A150: J149.1, U112.5
A151: J149.2, U112.4
A152: J149.4, U112.2
A153: J153.3, U115.3
A154: J153.1, U115.5
A155: J153.2, U115.4
A156: J153.4, U115.2
A157: J157.3, U118.3
A158: J157.1, U118.5
A159: J157.2, U118.4
A160: J157.4, U118.2
B1: J2.4, U1.13
B2: J2.3, U1.12
B3: J2.2, U1.11
B4: J2.1, U1.10
B5: J6.4, U4.13
B6: J6.2, U4.11
B7: J6.1, U4.10
B8: J6.3, U4.12
B9: J10.4, U7.13
B10: J10.2, U7.11
B11: J10.1, U7.10
B12: J10.3, U7.12
B13: J14.4, U10.13
B14: J14.2, U10.11
B15: J14.1, U10.10
B16: J14.3, U10.12
B17: J18.4, U13.13
B18: J18.2, U13.11
B19: J18.1, U13.10
B20: J18.3, U13.12
B21: J22.4, U16.13
B22: J22.2, U16.11
B23: J22.1, U16.10
B24: J22.3, U16.12
B25: J26.4, U19.13
B26: J26.2, U19.11
B27: J26.1, U19.10
B28: J26.3, U19.12
B29: J30.4, U22.13
B30: J30.2, U22.11
B31: J30.1, U22.10
B32: J30.3, U22.12
B33: J34.4, U25.13
B34: J34.2, U25.11
B35: J34.1, U25.10
B36: J34.3, U25.12
B37: J38.4, U28.13
B38: J38.2, U28.11
B39: J38.1, U28.10
B40: J38.3, U28.12
B41: J42.4, U31.13
B42: J42.2, U31.11
B43: J42.1, U31.10
B44: J42.3, U31.12
B45: J46.4, U34.13
B46: J46.2, U34.11
B47: J46.1, U34.10
B48: J46.3, U34.12
B49: J50.4, U37.13
B50: J50.2, U37.11
B51: J50.1, U37.10
B52: J50.3, U37.12
B53: J54.4, U40.13
B54: J54.2, U40.11
B55: J54.1, U40.10
B56: J54.3, U40.12
B57: J58.4, U43.13
B58: J58.2, U43.11
B59: J58.1, U43.10
B60: J58.3, U43.12
B61: J62.4, U46.13
B62: J62.2, U46.11
B63: J62.1, U46.10
B64: J62.3, U46.12
B65: J66.4, U49.13
B66: J66.2, U49.11
B67: J66.1, U49.10
B68: J66.3, U49.12
B69: J70.4, U52.13
B70: J70.2, U52.11
B71: J70.1, U52.10
B72: J70.3, U52.12
B73: J74.4, U55.13
B74: J74.2, U55.11
B75: J74.1, U55.10
B76: J74.3, U55.12
B77: J78.4, U58.13
B78: J78.2, U58.11
B79: J78.1, U58.10
B80: J78.3, U58.12
B81: J82.4, U61.13
B82: J82.2, U61.11
B83: J82.1, U61.10
B84: J82.3, U61.12
B85: J86.4, U64.13
B86: J86.2, U64.11
B87: J86.1, U64.10
B88: J86.3, U64.12
B89: J90.4, U67.13
B90: J90.2, U67.11
B91: J90.1, U67.10
B92: J90.3, U67.12
B93: J94.4, U70.13
B94: J94.2, U70.11
B95: J94.1, U70.10
B96: J94.3, U70.12
B97: J98.4, U73.13
B98: J98.2, U73.11
B99: J98.1, U73.10
B100: J98.3, U73.12
B101: J102.4, U76.13
B102: J102.2, U76.11
B103: J102.1, U76.10
B104: J102.3, U76.12
B105: J106.4, U79.13
B106: J106.2, U79.11
B107: J106.1, U79.10
B108: J106.3, U79.12
B109: J110.4, U82.13
B110: J110.2, U82.11
B111: J110.1, U82.10
B112: J110.3, U82.12
B113: J114.4, U85.13
B114: J114.2, U85.11
B115: J114.1, U85.10
B116: J114.3, U85.12
B117: J118.4, U88.13
B118: J118.2, U88.11
B119: J118.1, U88.10
B120: J118.3, U88.12
B121: J122.4, U91.13
B122: J122.2, U91.11
B123: J122.1, U91.10
B124: J122.3, U91.12
B125: J126.4, U94.13
B126: J126.2, U94.11
B127: J126.1, U94.10
B128: J126.3, U94.12
B129: J130.4, U97.13
B130: J130.2, U97.11
B131: J130.1, U97.10
B132: J130.3, U97.12
B133: J134.4, U100.13
B134: J134.2, U100.11
B135: J134.1, U100.10
B136: J134.3, U100.12
B137: J138.4, U103.13
B138: J138.2, U103.11
B139: J138.1, U103.10
B140: J138.3, U103.12
B141: J142.4, U106.13
B142: J142.2, U106.11
B143: J142.1, U106.10
B144: J142.3, U106.12
B145: J146.4, U109.13
B146: J146.2, U109.11
B147: J146.1, U109.10
B148: J146.3, U109.12
B149: J150.4, U112.13
B150: J150.2, U112.11
B151: J150.1, U112.10
B152: J150.3, U112.12
B153: J154.4, U115.13
B154: J154.2, U115.11
B155: J154.1, U115.10
B156: J154.3, U115.12
B157: J158.4, U118.13
B158: J158.2, U118.11
B159: J158.1, U118.10
B160: J158.3, U118.12
FB: R5.1, R6.2, U2.10
FB1: R7.2, R8.1, U5.10
FB2: R13.2, R14.1, U8.10
FB3: R19.2, R20.1, U11.10
FB4: R25.2, R26.1, U14.10
FB5: R31.2, R32.1, U17.10
FB6: R37.2, R38.1, U20.10
FB7: R43.2, R44.1, U23.10
FB8: R49.2, R50.1, U26.10
FB9: R55.2, R56.1, U29.10
FB10: R61.2, R62.1, U32.10
FB11: R67.2, R68.1, U35.10
FB12: R73.2, R74.1, U38.10
FB13: R79.2, R80.1, U41.10
FB14: R85.2, R86.1, U44.10
FB15: R91.2, R92.1, U47.10
FB16: R97.2, R98.1, U50.10
FB17: R103.2, R104.1, U53.10
FB18: R109.2, R110.1, U56.10
FB19: R115.2, R116.1, U59.10
FB20: R121.2, R122.1, U62.10
FB21: R127.2, R128.1, U65.10
FB22: R133.2, R134.1, U68.10
FB23: R139.2, R140.1, U71.10
FB24: R145.2, R146.1, U74.10
FB25: R151.2, R152.1, U77.10
FB26: R157.2, R158.1, U80.10
FB27: R163.2, R164.1, U83.10
FB28: R169.2, R170.1, U86.10
FB29: R175.2, R176.1, U89.10
FB30: R181.2, R182.1, U92.10
FB31: R187.2, R188.1, U95.10
FB32: R193.2, R194.1, U98.10
FB33: R199.2, R200.1, U101.10
FB34: R205.2, R206.1, U104.10
FB35: R211.2, R212.1, U107.10
FB36: R217.2, R218.1, U110.10
FB37: R223.2, R224.1, U113.10
FB38: R229.2, R230.1, U116.10
FB39: R235.2, R236.1, U119.10
GND: C1.2, C2.2, C3.2, C4.2, C5.2, C6.2, C7.-, D1.C, J3.1, J4.1, JP3.2, JP3.4, JP7.1, R2.1, R6.1, U1.7, U2.4, U2.9, U2.11, U2.12, U2.13, U2.14, U2.15, U3.2
GND1: C8.2, C9.2, C10.2, C11.2, C12.2, C13.2, C14.-, D2.C, J7.1, J8.1, JP1.1, JP2.2, JP2.4, R7.1, R10.1, U4.7, U5.4, U5.9, U5.11, U5.12, U5.13, U5.14, U5.15, U6.2
GND2: C15.2, C16.2, C17.2, C18.2, C19.2, C20.2, C21.-, D3.C, J11.1, J12.1, JP4.1, JP5.2, JP5.4, R13.1, R16.1, U7.7, U8.4, U8.9, U8.11, U8.12, U8.13, U8.14, U8.15, U9.2
GND3: C22.2, C23.2, C24.2, C25.2, C26.2, C27.2, C28.-, D4.C, J15.1, J16.1, JP6.1, JP8.2, JP8.4, R19.1, R22.1, U10.7, U11.4, U11.9, U11.11, U11.12, U11.13, U11.14, U11.15, U12.2
GND4: C29.2, C30.2, C31.2, C32.2, C33.2, C34.2, C35.-, D5.C, J19.1, J20.1, JP9.1, JP10.2, JP10.4, R25.1, R28.1, U13.7, U14.4, U14.9, U14.11, U14.12, U14.13, U14.14, U14.15, U15.2
GND5: C36.2, C37.2, C38.2, C39.2, C40.2, C41.2, C42.-, D6.C, J23.1, J24.1, JP11.1, JP12.2, JP12.4, R31.1, R34.1, U16.7, U17.4, U17.9, U17.11, U17.12, U17.13, U17.14, U17.15, U18.2
GND6: C43.2, C44.2, C45.2, C46.2, C47.2, C48.2, C49.-, D7.C, J27.1, J28.1, JP13.1, JP14.2, JP14.4, R37.1, R40.1, U19.7, U20.4, U20.9, U20.11, U20.12, U20.13, U20.14, U20.15, U21.2
GND7: C50.2, C51.2, C52.2, C53.2, C54.2, C55.2, C56.-, D8.C, J31.1, J32.1, JP15.1, JP16.2, JP16.4, R43.1, R46.1, U22.7, U23.4, U23.9, U23.11, U23.12, U23.13, U23.14, U23.15, U24.2
GND8: C57.2, C58.2, C59.2, C60.2, C61.2, C62.2, C63.-, D9.C, J35.1, J36.1, JP17.1, JP18.2, JP18.4, R49.1, R52.1, U25.7, U26.4, U26.9, U26.11, U26.12, U26.13, U26.14, U26.15, U27.2
GND9: C64.2, C65.2, C66.2, C67.2, C68.2, C69.2, C70.-, D10.C, J39.1, J40.1, JP19.1, JP20.2, JP20.4, R55.1, R58.1, U28.7, U29.4, U29.9, U29.11, U29.12, U29.13, U29.14, U29.15, U30.2
GND10: C71.2, C72.2, C73.2, C74.2, C75.2, C76.2, C77.-, D11.C, J43.1, J44.1, JP21.1, JP22.2, JP22.4, R61.1, R64.1, U31.7, U32.4, U32.9, U32.11, U32.12, U32.13, U32.14, U32.15, U33.2
GND11: C78.2, C79.2, C80.2, C81.2, C82.2, C83.2, C84.-, D12.C, J47.1, J48.1, JP23.1, JP24.2, JP24.4, R67.1, R70.1, U34.7, U35.4, U35.9, U35.11, U35.12, U35.13, U35.14, U35.15, U36.2
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

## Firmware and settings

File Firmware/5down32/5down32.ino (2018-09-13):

/*
Single Supply Logic Level Converter Hookup Guide

This project will beep continuosly with a frequency proportional 
to distance. As objects get closer, the beep gets faster. 

Hardware:
 HC-SR04 Ultrasonic Sensor 
 Arduino Pro Mini 3.3V/8MHz
 SparkFun Single Supply Logic Level Converter
 Piezo Buzzer

*/


#define TRIG_PIN 10
#define ECHO_PIN 11
#define Beep 3

void setup() {
  Serial.begin (9600);
  pinMode(TRIG_PIN, OUTPUT);
  digitalWrite(TRIG_PIN, LOW);
  pinMode(Beep, OUTPUT);
}

void loop() {
  unsigned long t1;
  unsigned long t2;
  unsigned long pulse_width;
  float cm1;


  // Hold the trigger pin high for at least 10 us
  digitalWrite(TRIG_PIN, HIGH);
  delayMicroseconds(10);
  digitalWrite(TRIG_PIN, LOW);

  // Wait for pulse on echo pin
  while (digitalRead(ECHO_PIN) == 0 );

  // Measure how long the echo pin was held high (pulse width)
  // Note: the micros() counter will overflow after ~70 min
  t1 = micros();
  while (digitalRead(ECHO_PIN) == 1);
  t2 = micros();
  pulse_width = t2 - t1;

  // Calculate distance in centimeters.
  cm1 = pulse_width*0.034/2;
  if (cm1 >= 200 || cm1 <= 0){
    Serial.println("Out of range");
  }
  else {
    Serial.print(cm1);
    Serial.println(" cm");

    tone(Beep,528); 
    delay(100);
    noTone(Beep);
    delay(cm1);
    

  }
}

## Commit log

2018-05-23 updated VOUT programming
    [Single_Supply_Logic_Level_Converter.brd, Single_Supply_Logic_Level_Converter.sch]
2018-05-23 Vout voltage from Vreg directly
    [Single_Supply_Logic_Level_Converter.brd]
2018-05-24 resizing board to 1x1 inch
    [Single_Supply_Logic_Level_Converter.brd]
2018-05-29 Adding top ground plane
    [Single_Supply_Logic_Level_Converter.brd]
2018-05-30 Updating design per review
    [Single_Supply_Logic_Level_Converter.brd, Single_Supply_Logic_Level_Converter.sch]
2018-05-31 New labels
    [Single_Supply_Logic_Level_Converter.brd, Single_Supply_Logic_Level_Converter.sch]
2018-05-31 Added text for warnings and jumper settings
    [Single_Supply_Logic_Level_Converter.brd, Single_Supply_Logic_Level_Converter.sch]
2018-06-04 adding buzzard labels
    [Single_Supply_Logic_Level_Converter.brd, Single_Supply_Logic_Level_Converter.sch]
2018-06-04 changing voltage output programming
    [Single_Supply_Logic_Level_Converter.brd, Single_Supply_Logic_Level_Converter.sch]
2018-06-04 adding measurements
    [Single_Supply_Logic_Level_Converter.brd]
2018-06-05 Updated per QC review
    [Single_Supply_Logic_Level_Converter.brd, Single_Supply_Logic_Level_Converter.sch]
2018-06-05 adding PROD ID prefix to 1.8M
    [Single_Supply_Logic_Level_Converter.brd, Single_Supply_Logic_Level_Converter.sch]
2018-06-06 Updated pin labels to SparkX standards
    [Single_Supply_Logic_Level_Converter.brd]
2018-06-20 increased labels size
    [Single_Supply_Logic_Level_Converter.brd]
2018-06-22 Decreased board width, moved R1/R2 resistors
    [Single_Supply_Logic_Level_Converter.brd]
2018-06-25 Updating schematic notes to include resistor values for VOUT programming
    [Single_Supply_Logic_Level_Converter.sch]
2018-06-26 updated version number
    [Single_Supply_Logic_Level_Converter.sch]
2018-06-26 Updated version number on brd file
    [Single_Supply_Logic_Level_Converter.brd]
2018-06-26 Updates per Engineering Design Review
    [Single_Supply_Logic_Level_Converter.brd, Single_Supply_Logic_Level_Converter.sch]
2018-06-26 Adding a lost fiducial
    [Single_Supply_Logic_Level_Converter.brd, Single_Supply_Logic_Level_Converter.sch]
2018-06-27 updated MIC5205(ADJ) part
    [Single_Supply_Logic_Level_Converter.brd, Single_Supply_Logic_Level_Converter.sch]
2018-07-11 v10 panel
    [Single_Supply_Logic_Level_Converter-Panel-Panel.brd]
2018-07-17 Updated gerbers with correct v-scores
    [Single_Supply_Logic_Level_Converter-Panel-Panel.brd, Single_Supply_Logic_Level_Converter-Panel.brd]
2018-07-25 added v-scores note
    [Single_Supply_Logic_Level_Converter-Panel.brd]
2018-08-07 Update 5down32.ino
    Update code for a Arduino Pro Mini 3.3V/8MHz.

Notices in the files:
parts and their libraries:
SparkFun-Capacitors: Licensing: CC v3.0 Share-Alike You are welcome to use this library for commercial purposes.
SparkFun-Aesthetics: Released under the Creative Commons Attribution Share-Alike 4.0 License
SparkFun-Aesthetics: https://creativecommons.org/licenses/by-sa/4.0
